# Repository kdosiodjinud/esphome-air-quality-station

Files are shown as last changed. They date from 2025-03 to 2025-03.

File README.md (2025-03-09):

# ESPHome Air Quality Station
ESPHome-powered portable air quality station with HomeAssistant integration

<p align="center">
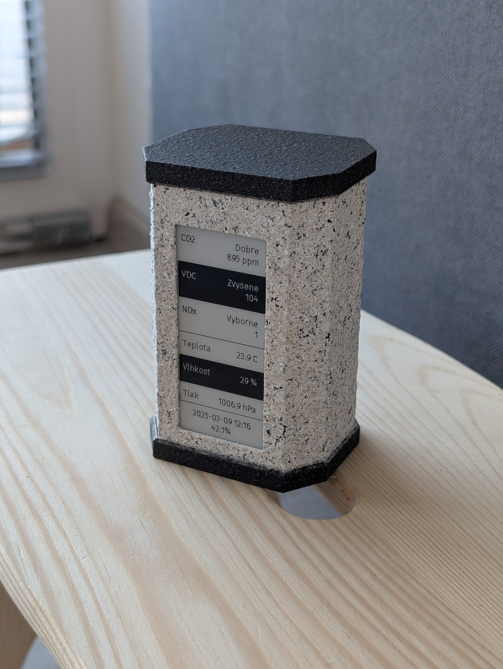
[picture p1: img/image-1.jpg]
  
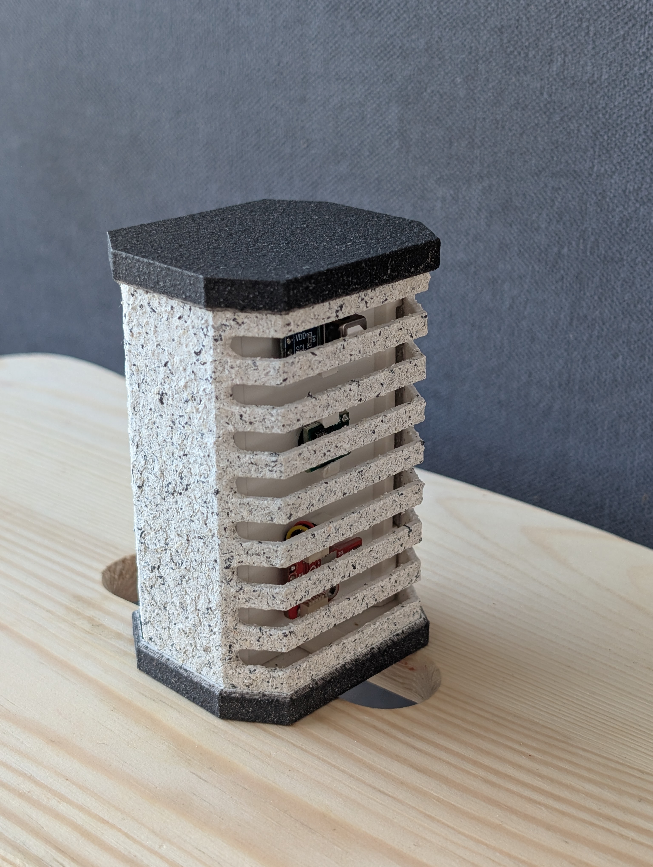
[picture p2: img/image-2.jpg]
  
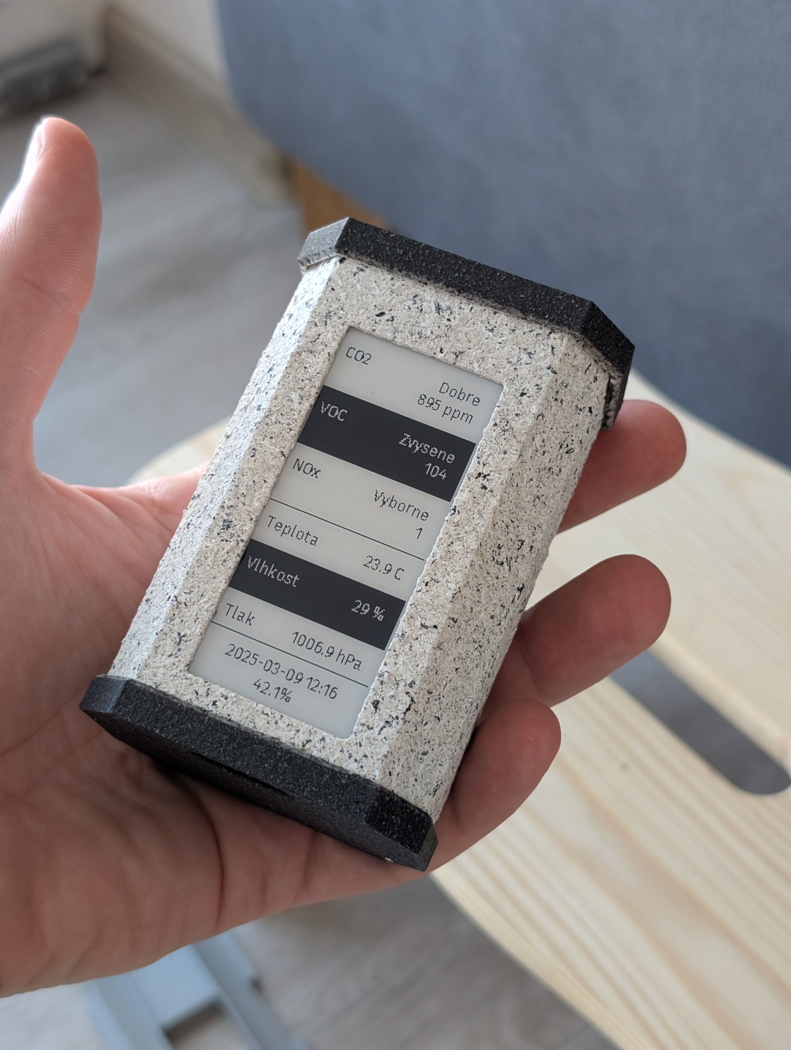
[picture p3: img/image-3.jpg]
  
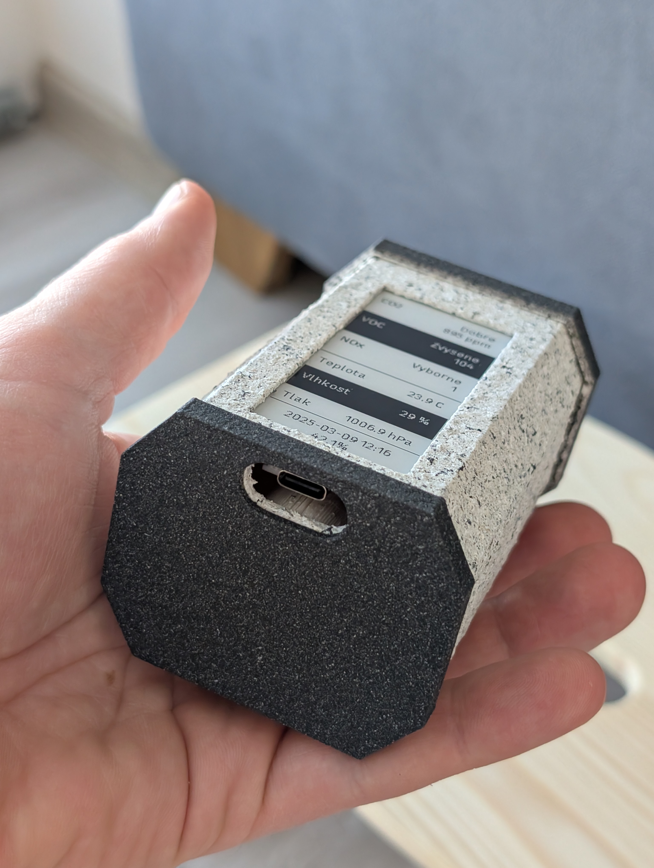
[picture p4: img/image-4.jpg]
  
</p>

<p align="center">
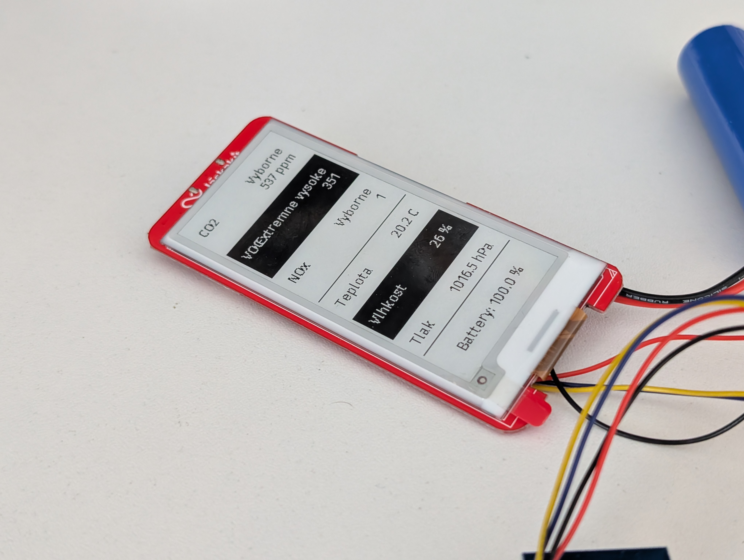
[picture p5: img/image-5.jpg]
  
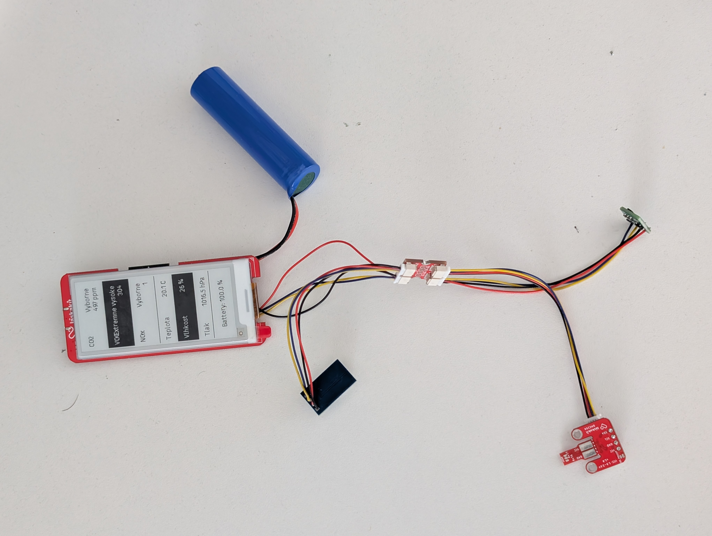
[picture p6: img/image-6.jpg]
  
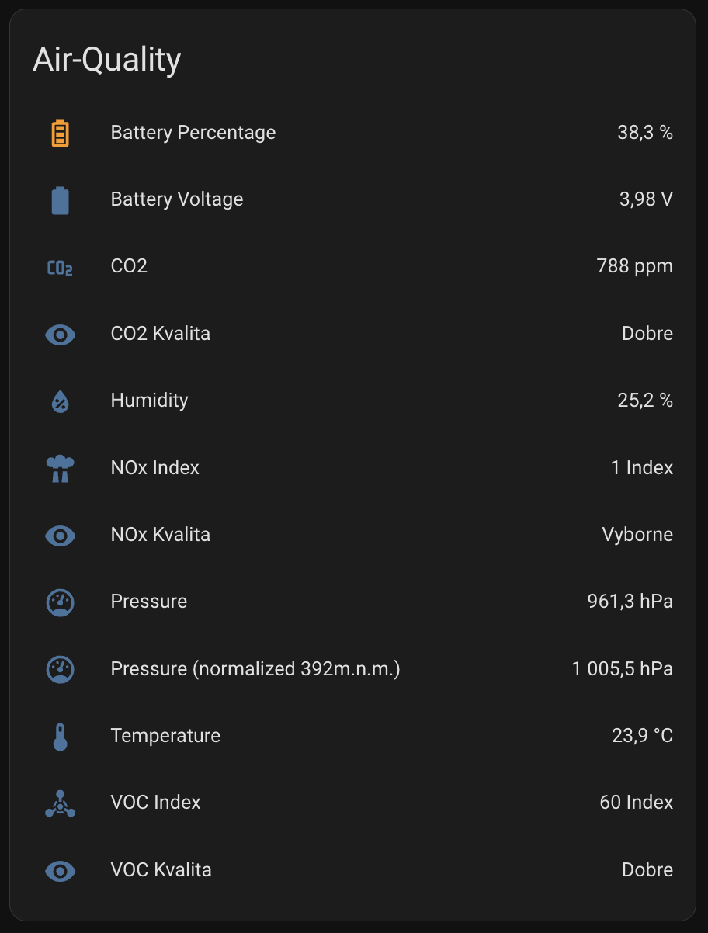
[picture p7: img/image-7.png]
  
</p>

## HW parts

### Co2 sensor + temperature + humidity
Czech shop (with easy connection by uSup) [https://www.laskakit.cz/laskakit-scd41-senzor-co2--teploty-a-vlhkosti-vzduchu/](https://www.laskakit.cz/laskakit-scd41-senzor-co2--teploty-a-vlhkosti-vzduchu/)

Better price but long delivery: [https://www.aliexpress.com/item/1005006619366785.html](https://www.aliexpress.com/item/1005006619366785.html)

_* from aliexpress select correct one_

### VOX / nOX
Czech shop (with easy connection by uSup): [https://www.laskakit.cz/laskakit-sgp41-voc-a-nox-senzor-kvality-ovzdusi/](https://www.laskakit.cz/laskakit-sgp41-voc-a-nox-senzor-kvality-ovzdusi/)

Better price but long delivery: [https://www.aliexpress.com/item/1005006749215421.html](https://www.aliexpress.com/item/1005006749215421.html)

_* from aliexpress select correct one_

### Pressure, temperature, humidity
Czech shop (with easy connection by uSup): [https://www.laskakit.cz/arduino-senzor-tlaku--teploty-a-vlhkosti-bme280/](https://www.laskakit.cz/arduino-senzor-tlaku--teploty-a-vlhkosti-bme280/)

Better price but long delivery: [https://www.aliexpress.com/item/1005006995581799.html](https://www.aliexpress.com/item/1005006995581799.html)

_* from aliexpress select correct one_

### ESP32 + display
Czech shop (with easy connection by uSup and battery connection): [https://www.laskakit.cz/laskakit-espink-shelf-2-9-esp32-e-paper/](https://www.laskakit.cz/laskakit-espink-shelf-2-9-esp32-e-paper/)

### Battery
Czech shop: [https://www.laskakit.cz/geb-li-ion-baterie-1x18650-1s1p-3-7v-3200mah/](https://www.laskakit.cz/geb-li-ion-baterie-1x18650-1s1p-3-7v-3200mah/)

### Cables with connectors
I2C bridge: [https://www.laskakit.cz/laskakit-sup-4x-na-dip-adapter/](https://www.laskakit.cz/laskakit-sup-4x-na-dip-adapter/)

10cm cable: [https://www.laskakit.cz/--sup--stemma-qt--qwiic-jst-sh-4-pin-kabel-10cm/](https://www.laskakit.cz/--sup--stemma-qt--qwiic-jst-sh-4-pin-kabel-10cm/)

Battery reduction: [https://www.laskakit.cz/jst-ph-2-2mm-do-jst-sh-2-1mm-adapter-pro-baterie--5cm/](https://www.laskakit.cz/jst-ph-2-2mm-do-jst-sh-2-1mm-adapter-pro-baterie--5cm/)

### 3D printed STL files

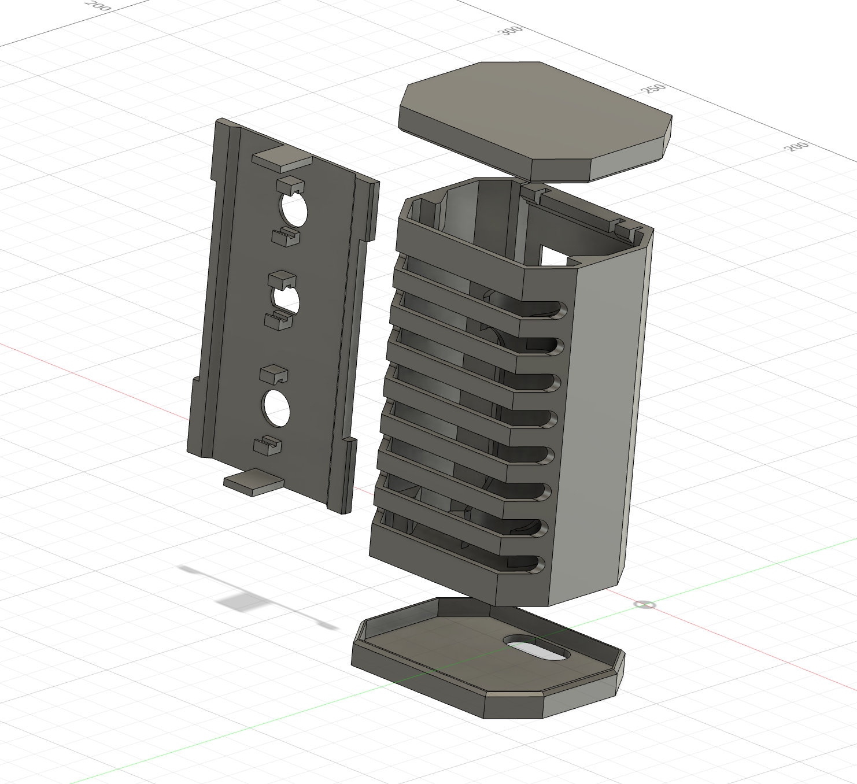
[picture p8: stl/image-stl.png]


* body: [download](./stl/co2-body.stl)
* desk: [download](./stl/co2-desk.stl)
* header: [download](./stl/co2-header.stl)
* footer: [download](./stl/co2-footer.stl)

### Post-production for 3D printed parts

* color in spray: [https://www.hornbach.cz/c/barvy-tapety-a-oblozeni-sten/barvy-laky/barvy/barvy-ve-spreji/specialni-efekty-ve-spreji/S12050/](https://www.hornbach.cz/c/barvy-tapety-a-oblozeni-sten/barvy-laky/barvy/barvy-ve-spreji/specialni-efekty-ve-spreji/S12050/)

### ESPHome config

[esp-config.yaml](./esp-config.yaml)

## Interesting

* I couldn't use deep sleep because the VOC sensor needs to collect values continuously
* I used a non-standard I2C - because I needed a perpetual I2C power supply
* I needed to modify the library for ePaper (you can see the link in the code)
* there is an extra sensor for temperature and humidity, because the CO2 sensor generates heat and does not measure properly
* device battery life is about 4 days (without VOC / NOX + deepsleep it would be more than a month)
* the display shows the pressure converted to a specific altitude
* values outside the optimum range are highlighted in black on the display
* if no wifi is available, it stops trying to use it - after reboot (usb-c power connection) it tries to find wifi again

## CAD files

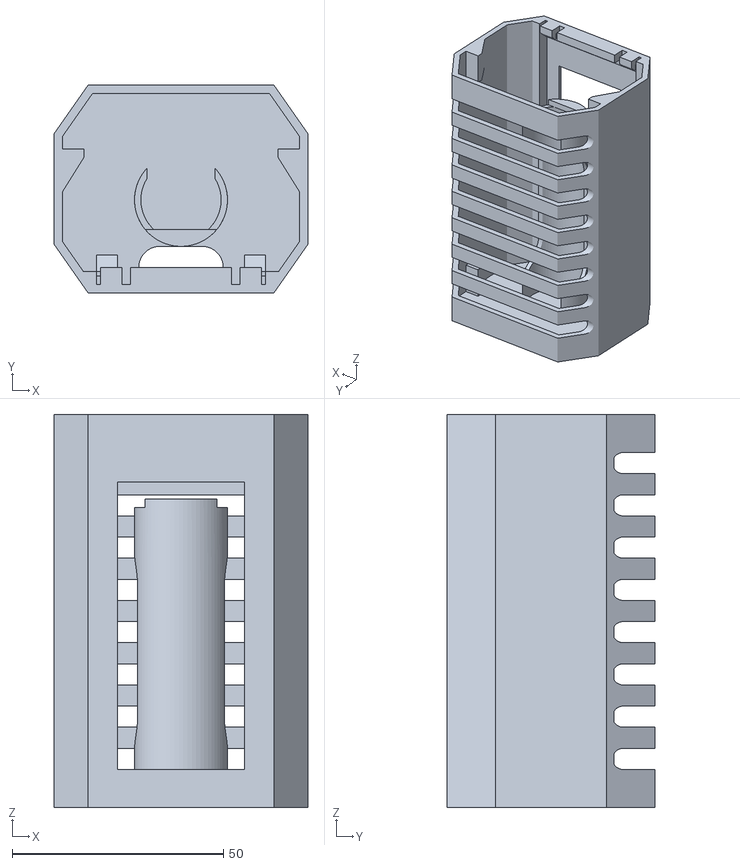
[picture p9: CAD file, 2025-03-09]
stl/co2-body.stl
60.0 x 49.1 x 93.0

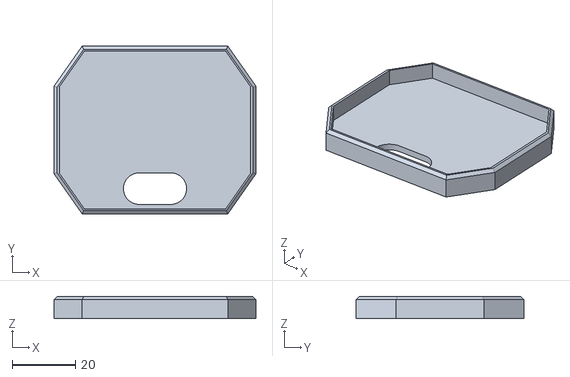
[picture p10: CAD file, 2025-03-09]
stl/co2-footer.stl
64.0 x 53.1 x 7.00

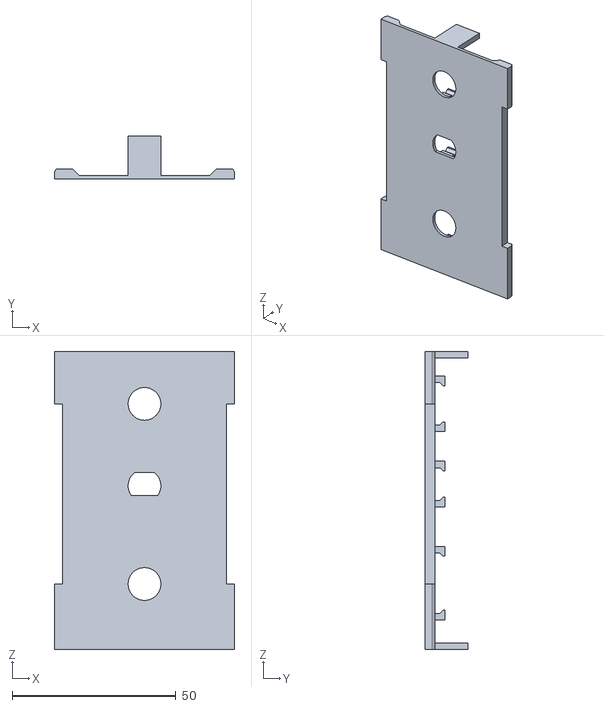
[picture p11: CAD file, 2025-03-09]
stl/co2-desk.stl
55.0 x 13.1 x 91.0

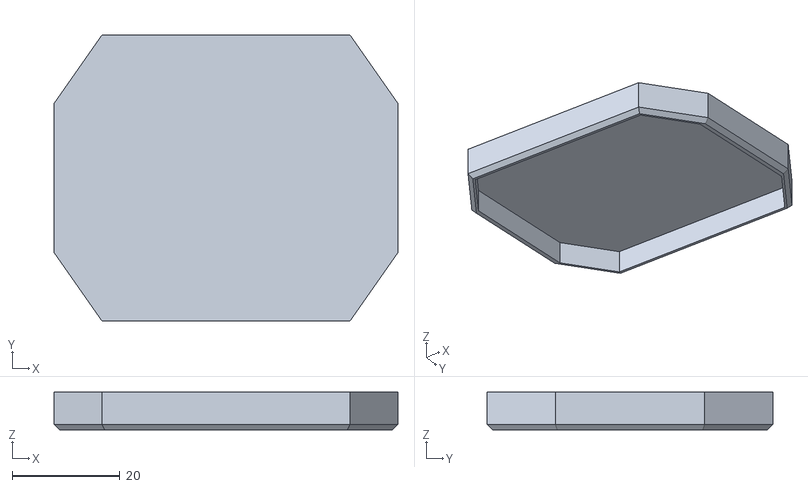
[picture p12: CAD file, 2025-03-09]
stl/co2-header.stl
64.0 x 53.1 x 7.00

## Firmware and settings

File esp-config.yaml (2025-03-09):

esphome:
  name: air-quality
  comment: "Měření kvality vzduchu - přenosné"
  on_boot:
    - priority: 600
      then:
        - output.turn_on: board_power  

esp32:
  board: esp-wrover-kit

external_components:
  - source:
      type: git
      url: https://github.com/kdosiodjinud/esphome/
      ref: main
    components: [ waveshare_epaper ]

logger:

api:
  encryption:
    key: "my-key"

ota:
  platform: esphome
  password: "my-password"

wifi:
  ssid: !secret wifi_ssid
  password: !secret wifi_password

i2c:
  sda: 32
  scl: 33
  id: bus_a
  frequency: 200khz

output:
  - platform: gpio
    pin: 2
    id: board_power

font:
  - file: 'FiraSans-Regular.ttf'
    id: font1
    size: 12

spi:
  clk_pin: 18
  mosi_pin: 23

time:
  - platform: sntp
    id: sntp_time
    timezone: Europe/Prague
    servers:
     - 0.pool.ntp.org
     - 1.pool.ntp.org
     - 2.pool.ntp.org

interval:
  - interval: 5min
    then:
      - if:
          condition:
            - lambda: return !id(wifi_failed);
          then:
            - wifi.configure:
                ssid: !secret wifi_ssid
                password: !secret wifi_password
                timeout: 20s
                on_error:
                  - lambda: id(wifi_failed) = true;
      - component.update: platform_scd4x
      - component.update: platform_sgp4x
      - component.update: battery_voltage
      - component.update: battery_percentage
      - component.update: platform_bme280_i2c
      - component.update: platform_bme280_i2c_pressure_normalized
      - delay: 5s
      - lambda: WiFi.mode(WIFI_OFF);
      - output.turn_on: board_power 
      - component.update: eink_display
      - delay: 3s
      - output.turn_off: board_power

display:
  - platform: waveshare_epaper
    id: eink_display
    cs_pin: 5
    dc_pin: 17
    reset_pin: 16
    model: gdey029t94
    rotation: 180
    update_interval: never
    lambda: |-
      id(eink_display).fill(COLOR_OFF); 

      if (id(platform_scd4x_co2).state > 1000) {
        id(eink_display).filled_rectangle(0, 0, 128, 50, COLOR_ON);
        id(eink_display).printf(5, 10, id(font1), COLOR_OFF, "CO2");
        id(eink_display).printf(118, 10, id(font1), COLOR_OFF, TextAlign::TOP_RIGHT, "%s", id(air_quality_co2).state.c_str());
        id(eink_display).printf(118, 25, id(font1), COLOR_OFF, TextAlign::TOP_RIGHT, "%.0f ppm", id(platform_scd4x_co2).state);
      } else {
        id(eink_display).printf(5, 10, id(font1), COLOR_ON, "CO2");
        id(eink_display).printf(118, 10, id(font1), COLOR_ON, TextAlign::TOP_RIGHT, "%s", id(air_quality_co2).state.c_str());
        id(eink_display).printf(118, 25, id(font1), COLOR_ON, TextAlign::TOP_RIGHT, "%.0f ppm", id(platform_scd4x_co2).state);
      }
      id(eink_display).line(0, 50, 128, 50);

      if (id(platform_sgp4x_voc).state > 100) {
        id(eink_display).filled_rectangle(0, 50, 128, 50, COLOR_ON);
        id(eink_display).printf(5, 60, id(font1), COLOR_OFF, "VOC");
        id(eink_display).printf(118, 60, id(font1), COLOR_OFF, TextAlign::TOP_RIGHT, "%s", id(air_quality_voc).state.c_str());
        id(eink_display).printf(118, 75, id(font1), COLOR_OFF, TextAlign::TOP_RIGHT, "%.0f", id(platform_sgp4x_voc).state);
      } else {
        id(eink_display).printf(5, 60, id(font1), COLOR_ON, "VOC");
        id(eink_display).printf(118, 60, id(font1), COLOR_ON, TextAlign::TOP_RIGHT, "%s", id(air_quality_voc).state.c_str());
        id(eink_display).printf(118, 75, id(font1), COLOR_ON, TextAlign::TOP_RIGHT, "%.0f", id(platform_sgp4x_voc).state);
      }
      id(eink_display).line(0, 100, 128, 100);

      if (id(platform_sgp4x_nox).state > 100) {
        id(eink_display).filled_rectangle(0, 100, 128, 50, COLOR_ON);
        id(eink_display).printf(5, 110, id(font1), COLOR_OFF, "NOx");
        id(eink_display).printf(118, 110, id(font1), COLOR_OFF, TextAlign::TOP_RIGHT, "%s", id(air_quality_nox).state.c_str());
        id(eink_display).printf(118, 125, id(font1), COLOR_OFF, TextAlign::TOP_RIGHT, "%.0f", id(platform_sgp4x_nox).state);
      } else {
        id(eink_display).printf(5, 110, id(font1), COLOR_ON, "NOx");
        id(eink_display).printf(118, 110, id(font1), COLOR_ON, TextAlign::TOP_RIGHT, "%s", id(air_quality_nox).state.c_str());
        id(eink_display).printf(118, 125, id(font1), COLOR_ON, TextAlign::TOP_RIGHT, "%.0f", id(platform_sgp4x_nox).state);
      }
      id(eink_display).line(0, 150, 128, 150);
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
